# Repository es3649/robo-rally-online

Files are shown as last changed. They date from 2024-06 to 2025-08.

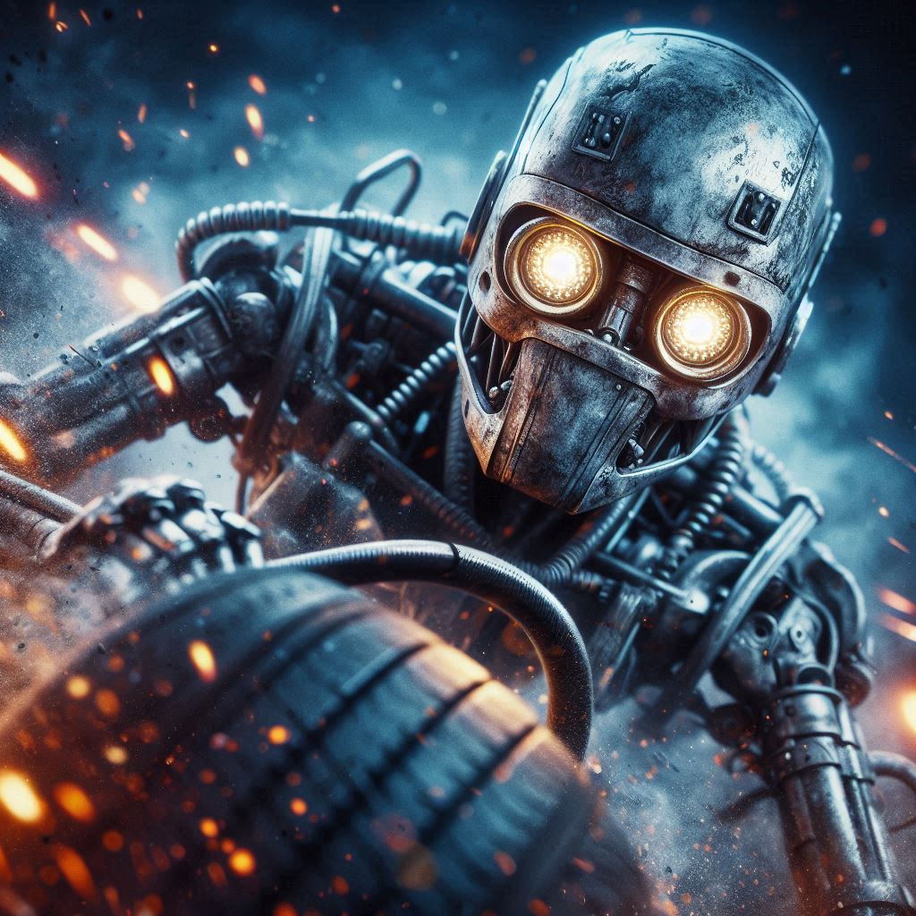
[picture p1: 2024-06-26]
shared/assets/robot_race2.jpg

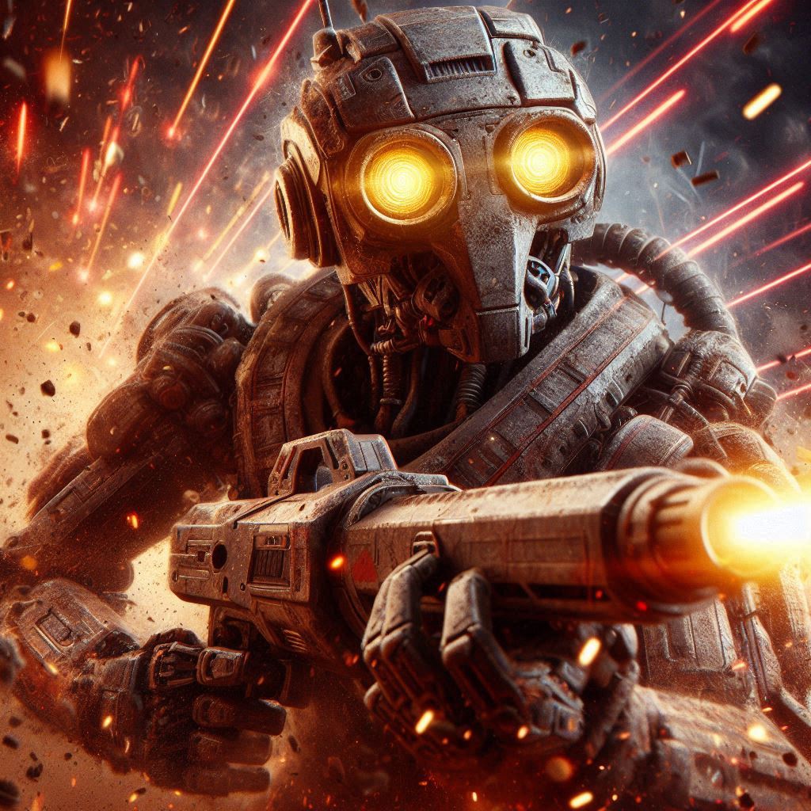
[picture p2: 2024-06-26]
shared/assets/robot_fighter.jpg

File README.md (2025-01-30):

# RoboRally Online

RoboRally Online is a Typescript/robotics implementation of the RoboRally board game, by Richard Garfield and Renegade Game Studio.

One day, while playing RoboRally, I thought to myself, _"How cool would it be if the robots on the board were actual robots, and I could actually program them?"_ so I decided to make it for real.
I started with a high-school physics knowledge of electronics, then read forums, watched videos, and bothered friends until I was able to figure out how to make it work.
This repository contains a majority of the files and code needed to bring the project to life.

**Disclaimer**: This project is not affiliated with nor endorsed by Richard Garfield nor Renegade Game Studio

## Contents

* [Contents](#contents)
* [Setup Instructions](#setup-instructions)
* [Project Structure](#project-structure)
    * [Player Client](#player-client)
    * [Host Application](#host-application)
    * [Bot Drivers](#bot-drivers)
    * [Schematics](#schematics)

## Setup Instructions

This project is the fullest stack application&mdash;all it's missing is a database.
Instructions for setting up a game (assuming the code is installed, running, and the bots are assembled) can be found in [playing.md](./doc/playing.md).
More comprehensive setup instructions, including instructions for setting up the execution environment and assembling bots, are provided in [setup.md](./doc/setup.md).

## Project Structure

The project is broken into 4 main parts:

* Player Client
* Host Application
* Bot Drivers
* Schematics

### Player Client

The Player Client, contained in the `player-client` directory, is a Vue+Vite+Pinia web application which provides a web interface for playing the game

### Host Application

The host application, in the `robo-rally-host` folder, is an Electron+Vite+Vue3 desktop application written in Typescript which provides an interface for starting the game, choosing some game settings, and managing Bluetooth connections with the robots.
It also contains a express-powered and socket.io-enabled server for hosting and joining games, and for handling communication with the players.
This server serves the Player Client.

### Bot Drivers

The bot drivers, in the `bot-drivers` directory, are a series of Arduino programs, designed to control robots over a Bluetooth connection managed by the host.

### Schematics

The `schematics` folder contains PCB and CAD schematics.

The PCB schematics are created using KiCad to model the custom boards used inside each robot.
For simplicity, there is one schematic to service all bots, and thus all robot features will be supported on each PCB.
Robots which do not support a certain feature, will simply have relevant components omitted, and will not have those components supported in their drivers.

CAD schematics are created in OnShape, and contain the 3D models for the robots.
Each of these is unique.

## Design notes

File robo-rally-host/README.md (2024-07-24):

# RoboRally Host

RoboRally Host is a desktop application made with Electron and Vite+Typescript.
It contains the Express server which serves up the compiled player-client files, it manages the websocket connections which the player-clients establish to send and receive game data, it runs the game server, and manages the Bluetooth connections to the robots.
It really is the workhorse of the entire system.

It is designed to be run on Raspberry Pi 5 with an attached touchscreen (1024x600 resolution)

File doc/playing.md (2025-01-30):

# Playing the Game

1. Connect the Pi and the players to the same Wi-Fi network
1. Set out the board
1. Start the application
1. Have the players join the game by scanning the QR code which appears on the console
    1. Players select bots and names
1. Power on the bots which will the players have selected
1. Start the game on the console
1. Follow prompts on the console to continue the game

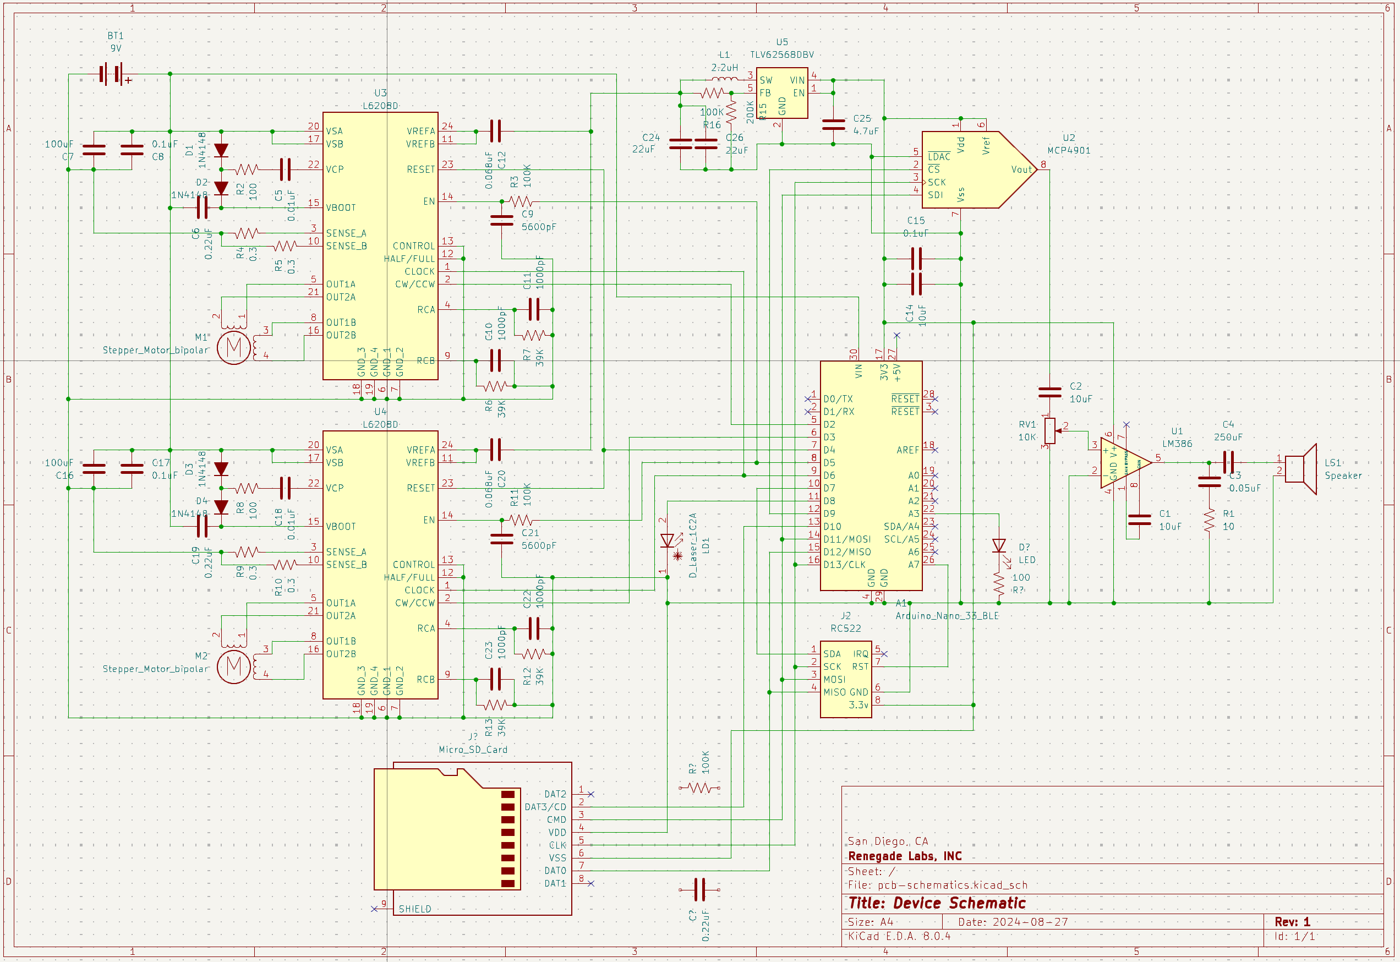
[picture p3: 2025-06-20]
player-client/src/assets/loading/schematic.png

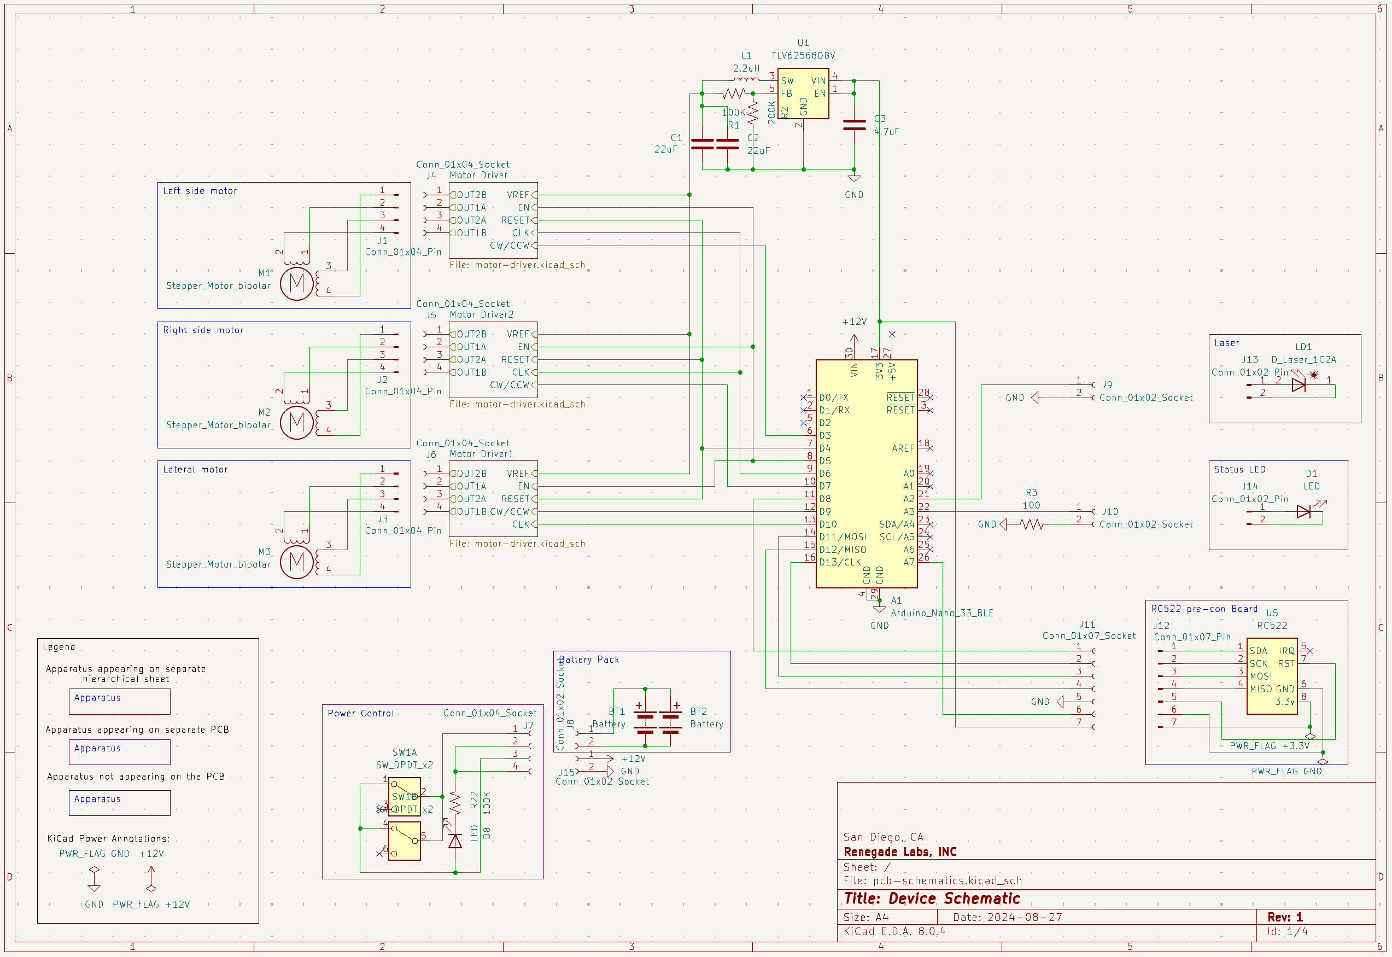
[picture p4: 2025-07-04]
player-client/src/assets/loading/schematic_sheet.png

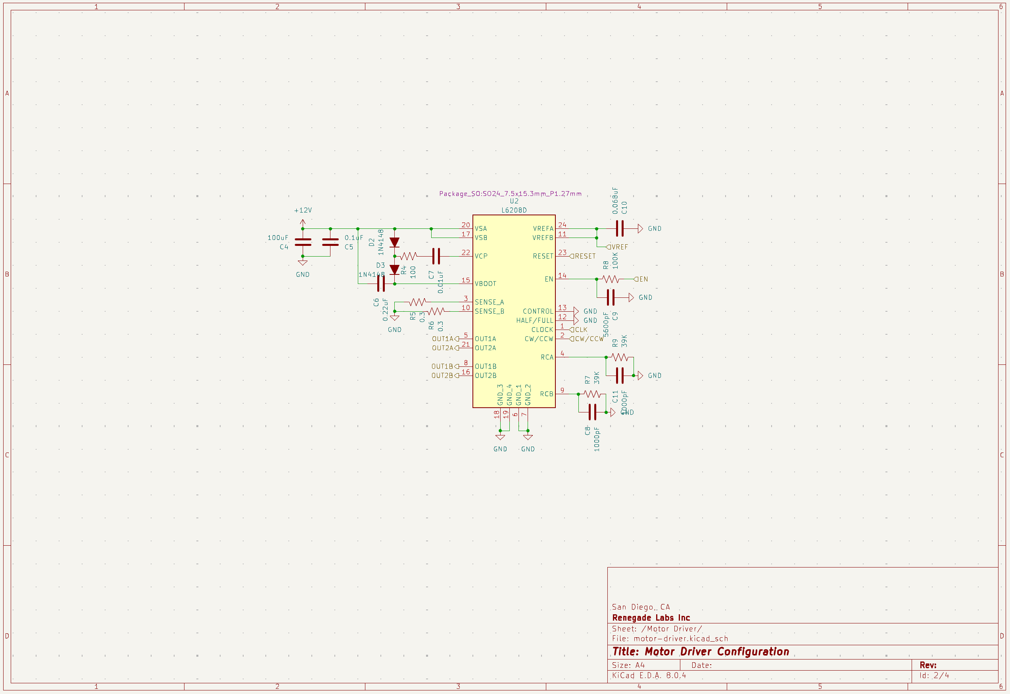
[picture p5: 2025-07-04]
player-client/src/assets/loading/motor_schematic_sheet.png

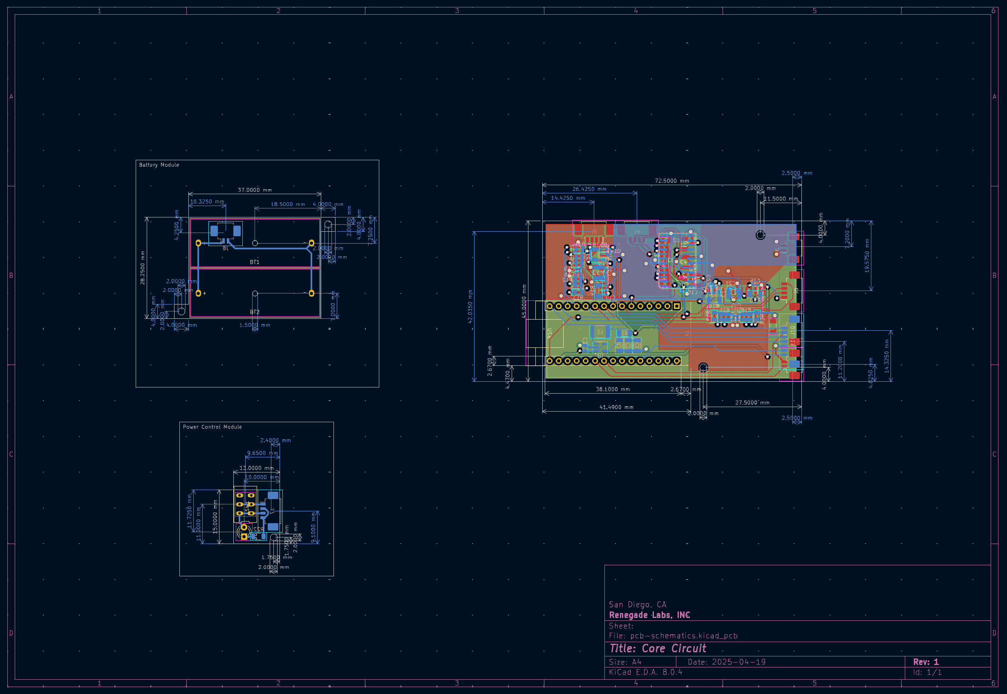
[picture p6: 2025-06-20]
player-client/src/assets/loading/PCB_sheet.png

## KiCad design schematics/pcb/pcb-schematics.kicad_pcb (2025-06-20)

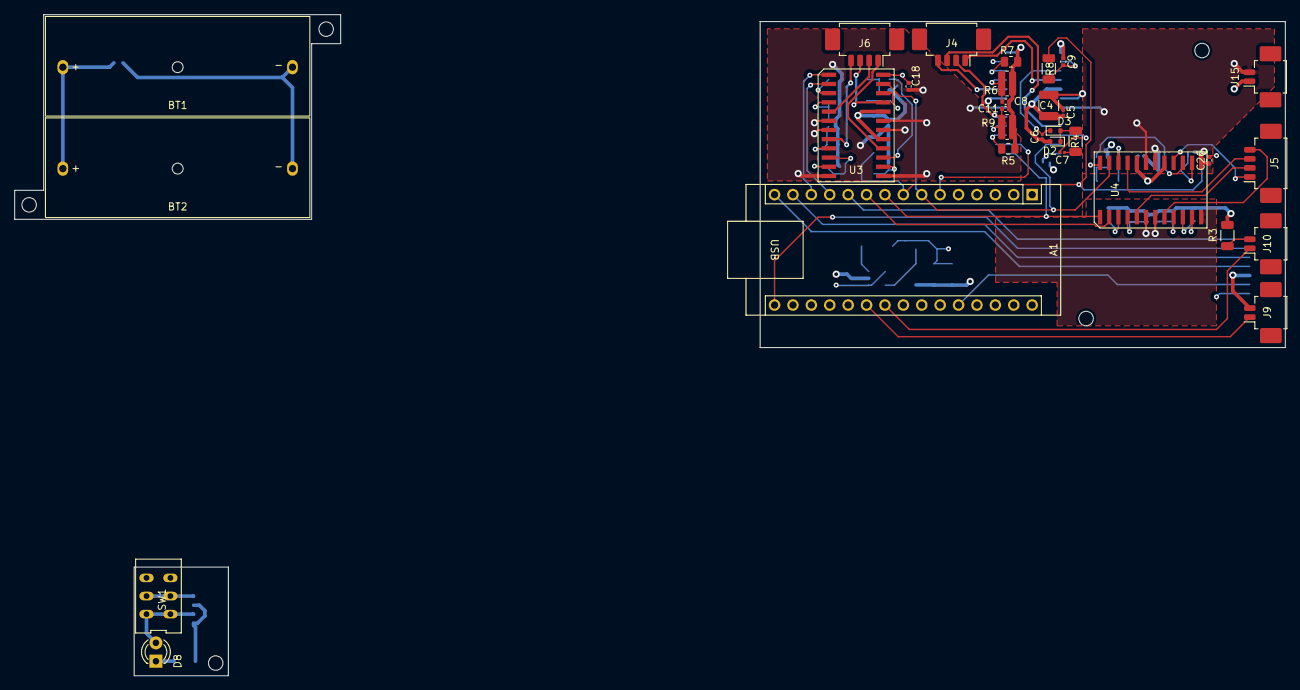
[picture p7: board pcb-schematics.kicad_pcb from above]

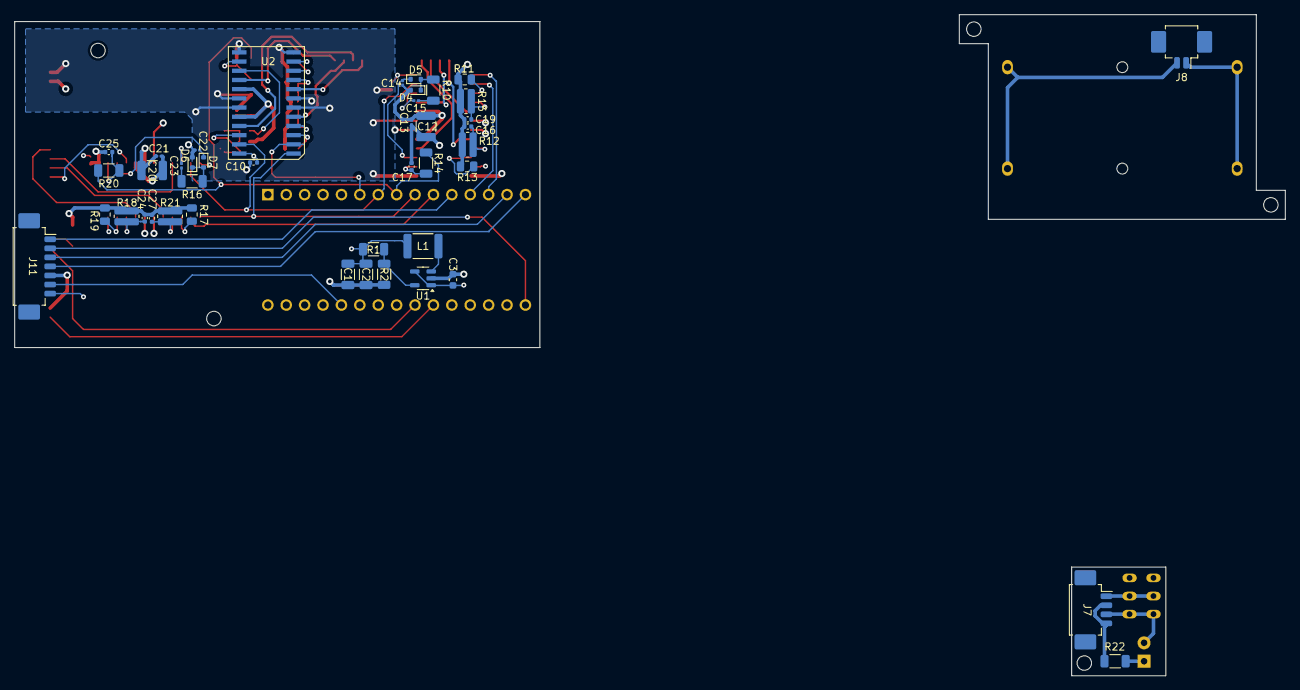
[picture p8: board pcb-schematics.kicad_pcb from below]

Board: 4 copper layers, 72.5 x 45.0 mm, 74 parts (43 on the bottom side), 66 nets.

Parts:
A1: Arduino_Nano_33_BLE; Arduino_Nano
BT1, BT2: Battery; Battery_clip-MPD_BHA23APC
C1, C2: 22uF; C_1206_3216Metric
C3: 4.7uF; C_0603_1608Metric
C4, C12, C20: 100uF; C_1210_3225Metric
C5, C13, C21: 0.1uF; C_0201_0603Metric_Pad0.64x0.40mm_HandSolder
C6, C14, C22: 0.22uF; C_0201_0603Metric
C7, C15, C23: 0.01uF; C_0201_0603Metric
C8, C11, C16, C19, C24, C27: 1000pF; C_0402_1005Metric
C9, C17, C25: 5600pF; C_0402_1005Metric
C10, C18, C26: 0.068uF; C_0402_1005Metric
D2, D3, D4, D5, D6, D7: 1N4148; D_SOD-523
D8: LED; LED_D3.0mm
J4, J5, J6, J7: Conn_01x04_Socket; Molex_PicoBlade_53261-0471_1x04-1MP_P1.25mm_Horizontal
J8, J9, J10, J15: Conn_01x02_Socket; Molex_PicoBlade_53261-0271_1x02-1MP_P1.25mm_Horizontal
J11: Conn_01x07_Socket; Molex_PicoBlade_53261-0771_1x07-1MP_P1.25mm_Horizontal
L1: 2.2uH; L_1812_4532Metric
R1, R8, R14, R20, R22: 100K; R_1206_3216Metric
R2: 200K; R_1206_3216Metric
R3, R4, R10, R16: 100; R_1206_3216Metric
R5, R6, R11, R12, R17, R18: 0.3; R_0805_2012Metric
R7, R9, R13, R15, R19, R21: 39K; R_0612_1632Metric
SW1: SW_DPDT_x2; SW-Slide_Diptronics-LSSA22
U1: TLV62568DBV; SOT-23-5
U2, U3, U4: L6208D; SO24_7.5x15.3mm_P1.27mm

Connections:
+12V: A1.30 (VIN), C4.2, C5.2, C6.1, C12.2, C13.2, C14.1, C20.2, C21.2, C22.1, D2.2 (A), D4.2 (A), D6.2 (A), J15.1, U2.17 (VSB), U2.20 (VSA), U3.17 (VSB), U3.20 (VSA), U4.17 (VSB), U4.20 (VSA)
/Motor Driver1/CLK: A1.13 (D10), U3.1 (CLOCK)
/Motor Driver1/CW/CCW: A1.12 (D9), U3.2 (CW/CCW)
/Motor Driver1/OUT1A: J6.2, U3.5 (OUT1A)
/Motor Driver1/OUT1B: J6.4, U3.8 (OUT1B)
/Motor Driver1/OUT2A: J6.3, U3.21 (OUT2A)
/Motor Driver1/OUT2B: J6.1, U3.16 (OUT2B)
/Motor Driver2/CW/CCW: A1.10 (D7), U4.2 (CW/CCW)
/Motor Driver2/OUT1A: J5.2, U4.5 (OUT1A)
/Motor Driver2/OUT1B: J5.4, U4.8 (OUT1B)
/Motor Driver2/OUT2A: J5.3, U4.21 (OUT2A)
/Motor Driver2/OUT2B: J5.1, U4.16 (OUT2B)
/Motor Driver/CLK: A1.9 (D6), U2.1 (CLOCK), U4.1 (CLOCK)
/Motor Driver/CW/CCW: A1.6 (D3), U2.2 (CW/CCW)
/Motor Driver/EN: A1.8 (D5), R8.2, R14.2, R20.2
/Motor Driver/OUT1A: J4.2, U2.5 (OUT1A)
/Motor Driver/OUT1B: J4.4, U2.8 (OUT1B)
/Motor Driver/OUT2A: J4.3, U2.21 (OUT2A)
/Motor Driver/OUT2B: J4.1, U2.16 (OUT2B)
/Motor Driver/RESET: A1.7 (D4), U2.23 (RESET), U3.23 (RESET), U4.23 (RESET)
/Motor Driver/VREF: C1.2, C2.2, C10.2, C18.2, C26.2, L1.1, R1.2, U2.11 (VREFB), U2.24 (VREFA), U3.11 (VREFB), U3.24 (VREFA), U4.11 (VREFB), U4.24 (VREFA)
GND: A1.4 (GND), A1.29 (GND), C1.1, C2.1, C3.2, C4.1, C5.1, C8.2, C9.1, C10.1, C11.2, C12.1, C13.1, C16.2, C17.1, C18.1, C19.2, C20.1, C21.1, C24.2, C25.1, C26.1, C27.2, J9.2, J11.5, J15.2, R2.1, R3.2, R5.1, R6.1, R7.2, R9.2, R11.1, R12.1, R13.2, R15.2, R17.1, R18.1, R19.2, R21.2, U1.2 (GND), U2.6 (GND_1), U2.7 (GND_2), U2.12 (HALF/FULL), U2.13 (CONTROL), U2.18 (GND_3), U2.19 (GND_4), U3.6 (GND_1), U3.7 (GND_2), U3.12 (HALF/FULL), U3.13 (CONTROL), U3.18 (GND_3), U3.19 (GND_4), U4.6 (GND_1), U4.7 (GND_2), U4.12 (HALF/FULL), U4.13 (CONTROL), U4.18 (GND_3), U4.19 (GND_4)
unnamed: A1.17 (3V3), C3.1, J11.7, U1.1 (EN), U1.4 (VIN)
unnamed: A1.21 (A2), J9.1
unnamed: A1.22 (A3), J10.1
unnamed: A1.26 (A7), J11.6
unnamed: A1.11 (D8), J11.1
unnamed: A1.14 (D11/MOSI), J11.3
unnamed: A1.15 (D12/MISO), J11.4
unnamed: A1.16 (D13/CLK), J11.2
unnamed: BT1.1 (+), BT2.1 (+), J8.1
unnamed: BT1.2 (-), BT2.2 (-), J8.2
unnamed: C7.1, R4.2
unnamed: C15.1, R10.2
unnamed: C23.1, R16.2
unnamed: D2.1 (K), D3.2 (A), R4.1
unnamed: C6.2, D3.1 (K), U2.15 (VBOOT)
unnamed: D4.1 (K), D5.2 (A), R10.1
unnamed: C14.2, D5.1 (K), U3.15 (VBOOT)
unnamed: D6.1 (K), D7.2 (A), R16.1
unnamed: C22.2, D7.1 (K), U4.15 (VBOOT)
unnamed: D8.2 (A), J7.3, SW1.1 (A), SW1.4 (A)
unnamed: D8.1 (K), R22.2
unnamed: J7.1, SW1.2 (B), SW1.5 (B)
unnamed: J7.2, J7.4, R22.1
unnamed: J10.2, R3.1
unnamed: R1.1, R2.2, U1.5 (FB)
unnamed: L1.2, U1.3 (SW)
unnamed: C9.2, R8.1, U2.14 (EN)
unnamed: C11.1, R9.1, U2.4 (RCA)
unnamed: C8.1, R7.1, U2.9 (RCB)
unnamed: R5.2, U2.3 (SENSE_A)
unnamed: R6.2, U2.10 (SENSE_B)
unnamed: C7.2, U2.22 (VCP)
unnamed: C17.2, R14.1, U3.14 (EN)
unnamed: C19.1, R15.1, U3.4 (RCA)
unnamed: C16.1, R13.1, U3.9 (RCB)
unnamed: R11.2, U3.3 (SENSE_A)
unnamed: R12.2, U3.10 (SENSE_B)
unnamed: C15.2, U3.22 (VCP)
unnamed: C25.2, R20.1, U4.14 (EN)
unnamed: C27.1, R21.1, U4.4 (RCA)
unnamed: C24.1, R19.1, U4.9 (RCB)
unnamed: R17.2, U4.3 (SENSE_A)
unnamed: R18.2, U4.10 (SENSE_B)
unnamed: C23.2, U4.22 (VCP)

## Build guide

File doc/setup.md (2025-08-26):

# Robo-Rally Online Setup

Setting up this project is super non-trivial

## Software

### Bluetooth

This project depends on the BlueZ package, which is the official Bluetooth driver for Linux development stacks.
It requires root privileges by default, so you will either need to run as root (rarely recommended), or else grant your user access to BlueZ by adding the following to `/etc/dbus-1/system.d/node-ble.conf`

```xml
<!DOCTYPE busconfig PUBLIC "-//freedesktop//DTD D-BUS Bus Configuration 1.0//EN"
  "http://www.freedesktop.org/standards/dbus/1.0/busconfig.dtd">
<busconfig>
  <policy user="__USERID__">
   <allow own="org.bluez"/>
    <allow send_destination="org.bluez"/>
    <allow send_interface="org.bluez.GattCharacteristic1"/>
    <allow send_interface="org.bluez.GattDescriptor1"/>
    <allow send_interface="org.freedesktop.DBus.ObjectManager"/>
    <allow send_interface="org.freedesktop.DBus.Properties"/>
  </policy>
</busconfig>
```

where `__USERID__` is replaces with the ID of the user which will be running the electron app.

### Port Access

The application hosts a webserver on the device.
Clients will try to access the server on port 80 (or 443 if I ever set up SSL, which I probably should).

To fix this, we ust host on 8199, and require a port forwarding on the host device to route traffic from 80 (or 443) to 8199.

On Linux, these can be set up using the `iptables` tool.
Start by enabling ip forwarding by adding this line to `/etc/sysctl.conf`
```
net.ipv4.ip_forward=1
```
then apply the changes with
```bash
sudo sysctl -p
```
Finally, apply the port forwarding rule by running
```bash
sudo iptables -t nat -A PREROUTING -p tcp --dport 80 -j REDIRECT --to-port 8199
```

If the `PORT` environment variable is set, then that port will be preferred over the process default of 8199.

### NodeJS

## Hardware

This is where things go crazy

### Motherboard Manufacture

### Bill of Materials

The following are required for assembly

* 1x Raspberry Pi 5 (or another Bluetooth-enabled Linux device)
* 6x Arduino Nano 33 BLE
* 6x Manufactured Motherboards
* 6x MicroSD cards (min 128MB)

TODO: Bill of materials for the chip

The following tools will also be needed for assembly, but will not be incorporated into the final product.

* 1x Micro-USB wire. The other end must attach to your development device (USB or USB-C)
* SMD Rework station, incl solder

### Arduino Programming

### Assembly

## Other Components

### Board

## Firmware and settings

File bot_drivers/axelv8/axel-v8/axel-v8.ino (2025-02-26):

#include <ArduinoBLE.h> // builtin
#include <SPI.h> // builtin
#include <MFRC522.h> // https://github.com/miguelbalboa/rfid

#define DEBUG true

#define BOT_NAME "Axel-V8"
#define STEPS_TO_MOVE_ONE_SPACE 100
#define STEPS_TO_ROTATE 100

#define STATUS_LED_PIN A3
#define RFID_RST_PIN A7
// #define SD_CS_PIN 10
#define DAC_CS_PIN 9
#define LASER_PIN 8
#define RFID_CS_PIN 7 
#define MTR_CLK_PIN 6
#define MTR_ENABLE_PIN 5
#define MTR_RESET_PIN 4
#define MTRL_ORIENTATION_PIN 2
#define MTRR_ORIENTATION_PIN 3

/**
 * States have the following LED status descriptions
 * CONNECTING: flashing quickly (~every 1/2 sec)    -_-_-_-_
 * DEFAULT: short flash every ~2 sec                -_______
 * SHUTDOWN: slowly breathing (~11s cycles)
 * LASER: same as DEFAULT, but the laser is on      -_______
 * RFID: two quick pulses, followed by ~1s off      -_-_____
 * ERROR: flashing slowly (~every 2 sec)            ----____
 */
namespace State {
  const uint8_t DEFAULT = 1;
  const uint8_t SHUTDOWN = 2;
  const uint8_t LASER = 3;
  const uint8_t RFID = 4;
};

uint8_t cur_state = State::DEFAULT;
uint8_t last_idempotence_code = 0;

namespace Movement {
  const uint8_t NONE = 0;
  const uint8_t MOVE_FORWARD = 1;
  const uint8_t MOVE_BACK = 2;
  const uint8_t MOVE_LEFT = 3;
  const uint8_t MOVE_RIGHT = 4;
  const uint8_t TURN_LEFT = 5;
  const uint8_t TURN_RIGHT = 6;
};

uint8_t movement = Movement::NONE;
int steps;

/******************************* BLUETOOTH SETUP *******************************/
// define the UUIDs for our characteristics
const char* SERVICE_ID                          = "346642f1-0000-49fc-a6a6-8a782eb06f26";
const char* STATE_CHARACTERISTIC                = "346642f1-0001-49fc-a6a6-8a782eb06f26";
const char* SOUND_CHARACTERISTIC                = "346642f1-0002-49fc-a6a6-8a782eb06f26";
const char* MOVEMENT_DIRECTION_CHARACTERISTIC   = "346642f1-0003-49fc-a6a6-8a782eb06f26";
const char* IDEMPOTENCY_CHARACTERISTIC          = "346642f1-0004-49fc-a6a6-8a782eb06f26";
const char* RFID_CHARACTERISTIC                 = "346642f1-0005-49fc-a6a6-8a782eb06f26";

BLEService controlService(SERVICE_ID);
BLEByteCharacteristic stateCharacteristic(STATE_CHARACTERISTIC, BLERead);
BLEByteCharacteristic soundCharacteristic(SOUND_CHARACTERISTIC, BLERead);
BLEByteCharacteristic movementDirectionCharacteristic(MOVEMENT_DIRECTION_CHARACTERISTIC, BLERead);
BLEByteCharacteristic idempotencyCharacteristic(IDEMPOTENCY_CHARACTERISTIC, BLERead);
BLEUnsignedIntCharacteristic rfidCharacteristic(RFID_CHARACTERISTIC, BLEWrite);

BLEDevice central;

void connect() {
  // if not initialized: initialize
  BLE.advertise();

  // flash the STATUS LED quickly while awaiting a connection
  do {
    central = BLE.central();
    digitalWrite(STATUS_LED_PIN, !digitalRead(STATUS_LED_PIN));
    delay(500);
  } while (!central);

  BLE.stopAdvertise();

  #ifdef DEBUG
    Serial.println("Connected to central device!");
    Serial.print("MAC Address: ");
    Serial.println(central.address());
  #endif

  updateBLEValues();
}

void updateBLEValues() {
  // check if the state code changed
  uint8_t written_idempotency;
  idempotencyCharacteristic.readValue(written_idempotency);

  if (written_idempotency != last_idempotence_code) {
    // update all the values
    stateCharacteristic.readValue(cur_state);
    movementDirectionCharacteristic.readValue(movement);
    last_idempotence_code = written_idempotency;
    if (movement != Movement::NONE) {
      move();
    }

    #ifdef DEBUG
      Serial.print("Read state: ");
      Serial.println(cur_state);
      Serial.print("Read movement: ");
      Serial.println(movement);
    #endif
  }
}

/******************************* RFID READER SETUP *******************************/
MFRC522 rfid(RFID_CS_PIN, RFID_RST_PIN); 

void readRFID() {
  static byte nuid_PICC[4];
  // if there is no card present, or we can't read it, continue
  if(!rfid.PICC_IsNewCardPresent() || !rfid.PICC_ReadCardSerial()) {
    return;
  }

  // check if this is a recognized card type
  MFRC522::PICC_Type picc_type = rfid.PICC_GetType(rfid.uid.sak);
  if (picc_type != MFRC522::PICC_TYPE_MIFARE_MINI &&
      picc_type != MFRC522::PICC_TYPE_MIFARE_1K &&
      picc_type != MFRC522::PICC_TYPE_MIFARE_4K) {
    return;
  }

  // if any byte is different, we actually got a new code
  if (rfid.uid.uidByte[0] != nuid_PICC[0] || 
      rfid.uid.uidByte[1] != nuid_PICC[1] || 
      rfid.uid.uidByte[2] != nuid_PICC[2] || 
      rfid.uid.uidByte[3] != nuid_PICC[3] ) {
    #ifdef DEBUG
      Serial.print("Detected new card. NUID tag is: ");
      Serial.println();
    #endif
    // save the most recent code
    uint32_t value = 0;
    for (uint8_t i = 0; i < 4; i++) {
      value <<= 8;
      nuid_PICC[i] = rfid.uid.uidByte[i];
      value |= rfid.uid.uidByte[i];
    }

    // write the new card value to the bluetooth characteristic
    rfidCharacteristic.writeValue(value);
  }
}

/******************************* L6208 DRIVER SETUP *******************************/
// TODO tune this: I think the technical minimum in the datasheet is 1us, but that's probably too short
#define MOTOR_STEP_DELAY_US 1000
inline void disableMotors() {
  digitalWrite(MTR_ENABLE_PIN, LOW);
}

inline void enableMotors() {
  digitalWrite(MTR_ENABLE_PIN, HIGH);
  // there is a max 1050ns delay we will need to respect before sending data signals
  delayMicroseconds(2);
}

inline void setMotorClockwise(const uint8_t& controller_pin) {
  digitalWrite(controller_pin, HIGH);
}

inline void setMotorWiddershins(const uint8_t& controller_pin) {
  digitalWrite(controller_pin, LOW);
}

void move() {
  if (movement == Movement::MOVE_FORWARD || movement == Movement::TURN_RIGHT) {
    // left motor needs to move clockwise
    setMotorClockwise(MTRL_ORIENTATION_PIN);
  } else {
    // needs to move widdershins
    setMotorWiddershins(MTRL_ORIENTATION_PIN);
  }

  if (movement == Movement::MOVE_BACK || movement == Movement::TURN_RIGHT) {
    // right motor needs to move clockwise
    setMotorClockwise(MTRR_ORIENTATION_PIN);
  } else {
    // right motor needs to move widdershins
    setMotorWiddershins(MTRR_ORIENTATION_PIN);
  }

  if (movement == Movement::MOVE_FORWARD || movement == Movement::MOVE_BACK) {
    steps = STEPS_TO_MOVE_ONE_SPACE;
  } else {
    steps = STEPS_TO_ROTATE;
  }

  // enable the motors
  enableMotors();
}

void moveStep() {
  // use the correct number of steps for forward/back movement, lateral movement, or rotation
  static int steps_taken = 0;

  // begin rotating the motors
  if (steps_taken < steps) {
    PinStatus clk_state = digitalRead(MTR_CLK_PIN);
    digitalWrite(MTR_CLK_PIN, !clk_state);
    delayMicroseconds(MOTOR_STEP_DELAY_US);
    if (clk_state == LOW) {
      steps_taken++;
    }
  } else {
    // set the clock low
    disableMotors();
    // set that there's no movement
    movement = Movement::NONE;
    // reset the step counts
    steps = 0;
    steps_taken = 0;
  }
}

/******************************* ERROR STATE DEFN *******************************/
/**
 * perpetually goes into an error state
 * (use only when an un-resolvable error occurs)
 */
void errorState() {
  while (1) {
    digitalWrite(STATUS_LED_PIN, HIGH);
    delay(2000);
    digitalWrite(STATUS_LED_PIN, HIGH);
    delay(2000);
  }
}

/******************************* SHUTDOWN STATE DEFN *******************************/
void shutdown() {
  // later: play a shutdown noise

  static int step = 1;
  static uint8_t intensity = 0;
  analogWrite(STATUS_LED_PIN, intensity);
  
  delay(10);
  if (intensity < 255 && intensity > 0) {
    intensity += step;
    analogWrite(STATUS_LED_PIN, intensity);
  } else {
    step *= -1;
  }

  // sometimes we still need to move while shutdown
  if (steps) {
    moveStep();
  }
}

/******************************* LASER STATE DEFN *******************************/
void laser() {
  // light off; laser on
  digitalWrite(STATUS_LED_PIN, LOW);
  digitalWrite(LASER_PIN, HIGH);

  // laser off, back to default
  digitalWrite(LASER_PIN, LOW);
  cur_state = State::DEFAULT;
}

/******************************* DEFAULT STATE DEFN *******************************/
void statusLEDUpdate() {
  static int last_status_led_swap = 0;
  int now = millis();
  PinStatus led_status = digitalRead(STATUS_LED_PIN);
  int diff = now - last_status_led_swap;
  switch (cur_state) {
    case State::DEFAULT:
    case State::LASER:
      if (diff < 250) {
        digitalWrite(STATUS_LED_PIN, HIGH);
      } else {
        digitalWrite(STATUS_LED_PIN, LOW);
      }
      break;
    case State::RFID:
      if (diff < 250) {
        digitalWrite(STATUS_LED_PIN, HIGH);
      } else if (diff > 250) {
        digitalWrite(STATUS_LED_PIN, LOW);
      } else if (diff > 500) {
        digitalWrite(STATUS_LED_PIN, HIGH);
      } else if (diff > 750) {
        digitalWrite(STATUS_LED_PIN, LOW);
      }
      break;
  }

  if (diff > 2000) {
    last_status_led_swap = now;
  }
}

void defaultState() {
  statusLEDUpdate();

  if (movement != Movement::NONE) {
    moveStep();
  }
}

/******************************* SETUP AND LOOP *******************************/
void setup() {
  pinMode(STATUS_LED_PIN, OUTPUT);
  pinMode(RFID_RST_PIN, OUTPUT);
  pinMode(LASER_PIN, OUTPUT);
  pinMode(RFID_CS_PIN, OUTPUT);
  pinMode(MTR_CLK_PIN, OUTPUT);
  pinMode(MTR_RESET_PIN, OUTPUT);
  digitalWrite(MTR_RESET_PIN, HIGH);
  pinMode(MTR_ENABLE_PIN, OUTPUT);
  disableMotors();
  pinMode(MTRL_ORIENTATION_PIN, OUTPUT);
  pinMode(MTRR_ORIENTATION_PIN, OUTPUT);

  digitalWrite(STATUS_LED_PIN, HIGH);
  
  
  #ifdef DEBUG
    Serial.begin(9600);
    while (!Serial) {}
    Serial.println("Resetting L6208(s)");
  #endif

  // hold the reset pin low for >1us, then raise it again
  digitalWrite(MTR_RESET_PIN, LOW);
  delayMicroseconds(15);
  digitalWrite(MTR_RESET_PIN, HIGH);

  #ifdef DEBUG
    Serial.println("L6208(s) reset");
    Serial.println("Initializing RFID reader");
  #endif
  // setup the RFID reader
  SPI.begin();
  rfid.PCD_Init();

  #ifdef DEBUG
    Serial.println("RFID reader ready");
    Serial.println("Starting Bluetooth® Low Energy");
  #endif

  if(!BLE.begin()) {
  #ifdef DEBUG
      Serial.println("Failed to start Bluetooth®!");
  #endif
    errorState();
  }

  BLE.setLocalName(BOT_NAME);
  BLE.setAdvertisedService(controlService);
  controlService.addCharacteristic(stateCharacteristic);
  controlService.addCharacteristic(soundCharacteristic);
  controlService.addCharacteristic(movementDirectionCharacteristic);
  controlService.addCharacteristic(idempotencyCharacteristic);
  controlService.addCharacteristic(rfidCharacteristic);

  stateCharacteristic.writeValue(-1);
  #ifdef DEBUG
    Serial.println("Bluetooth® Low Energy initialized");
  #endif

  // start connecting
  connect();
}

void loop() {
  // check the connection status, if we were disconnected, return to pairing mode
  if (!central.connected()) {
    // switch back to connecting state
    connect();
  } else {
    // update values from BLE
    updateBLEValues();
  }

  statusLEDUpdate();

  switch (cur_state) {
  case State::DEFAULT:
    defaultState();
    break;
  case State::SHUTDOWN:
    shutdown();
    break;
  case State::LASER:
    laser();
    break;
  case State::RFID:
    readRFID();
    break;
  default:
    cur_state = State::DEFAULT;
    break;
  }
}

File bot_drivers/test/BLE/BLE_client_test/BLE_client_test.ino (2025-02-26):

// we set up the Arduino as a BLE peripheral device
// Code is adapted from a public-domain Arduino tutorial
// https://docs.arduino.cc/tutorials/nano-33-ble-sense/ble-device-to-device/

#include <ArduinoBLE.h>

// #define DEBUG

#define RED_PIN A0
#define GREEN_PIN A2
#define BLUE_PIN A4
#define STATUS_PIN 13

const char* SERVICE_ID                          = "346642f1-48ef-0000-a6a6-8a782eb06f26";
const char* RED_CHARACTERISTIC                  = "346642f1-48ef-0001-a6a6-8a782eb06f26";
const char* GREEN_CHARACTERISTIC                = "346642f1-48ef-0002-a6a6-8a782eb06f26";
const char* BLUE_CHARACTERISTIC                 = "346642f1-48ef-0003-a6a6-8a782eb06f26";


BLEService controlService(SERVICE_ID);
BLEByteCharacteristic redCharacteristic(RED_CHARACTERISTIC, BLERead | BLEWrite);
BLEByteCharacteristic greenCharacteristic(GREEN_CHARACTERISTIC, BLERead | BLEWrite);
BLEByteCharacteristic blueCharacteristic(BLUE_CHARACTERISTIC, BLERead | BLEWrite);

void setup() {
  pinMode(RED_PIN, OUTPUT);
  pinMode(GREEN_PIN, OUTPUT);
  pinMode(BLUE_PIN, OUTPUT);

  analogWrite(RED_PIN, 128);
  delay(500);
  analogWrite(GREEN_PIN, 128);
  delay(500);
  analogWrite(BLUE_PIN, 128);
  delay(500);
  analogWrite(RED_PIN, 255);
  delay(500);
  analogWrite(GREEN_PIN, 255);
  delay(500);
  analogWrite(BLUE_PIN, 255);
  delay(500);
  analogWrite(RED_PIN, 0);
  analogWrite(GREEN_PIN, 0);
  analogWrite(BLUE_PIN, 0);

#ifdef DEBUG
  Serial.begin(9600);
  // wait for serial connection
  while (!Serial);
#endif

  if (!BLE.begin()) {
#ifdef DEBUG
    Serial.println("- Starting Bluetooth® Low Energy module failed!");
#endif
    while (1);
  }

  BLE.setLocalName("Arduino Nano 33 BLE (peripheral)");
  BLE.setAdvertisedService(controlService);
  controlService.addCharacteristic(redCharacteristic);
  controlService.addCharacteristic(greenCharacteristic);
  controlService.addCharacteristic(blueCharacteristic);
  BLE.addService(controlService);
  redCharacteristic.writeValue(0);
  greenCharacteristic.writeValue(0);
  blueCharacteristic.writeValue(0);
  digitalWrite(STATUS_PIN, HIGH);
  BLE.advertise();


#ifdef DEBUG
  Serial.println("Arduino Nano 33 BLE (Peripheral Device)");
  Serial.println("  ");
#endif
}

void loop() {
  BLEDevice central = BLE.central();
#ifdef DEBUG
  Serial.println("- Discovering Central Device");
#endif
  delay(500);

  if (central) {
    digitalWrite(STATUS_PIN, LOW);
#ifdef DEBUG
    Serial.println("* Connected to central device!");
    Serial.print("* Device MAC address: ");
    Serial.println(central.address());
    Serial.println("  ");
#endif

    while (central.connected()) {
      if (redCharacteristic.written()) {
        analogWrite(RED_PIN, redCharacteristic.value());
      }
      if (greenCharacteristic.written()) {
        analogWrite(GREEN_PIN, greenCharacteristic.value());
      }
      if (blueCharacteristic.written()) {
        analogWrite(BLUE_PIN, blueCharacteristic.value());
      }
    }

#ifdef DEBUG
    Serial.println("* Disconnected from central device!");
#endif
    digitalWrite(STATUS_PIN, HIGH);
    analogWrite(RED_PIN, 0);
    analogWrite(GREEN_PIN, 0);
    analogWrite(BLUE_PIN, 0);
  }
}

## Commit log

2024-07-02 wire up host.vue
2024-08-06 added board data models and board data files
2024-08-14 Data model work for movements and boards
2024-08-16 adds board loader and renderer
2024-08-22 socket connection is active
2024-10-14 changed orientation of turning conveyors
    outgoing direction is always forward
2024-10-17 adds hardware files
    also updates a test
    [pcb-schematics.kicad_pcb, pcb-schematics.kicad_sch]
2024-10-18 adds conv_LR and board_loader tests
2024-10-18 add test data boards
2024-10-27 added tests and board element activation
2024-11-22 schematic and driver rewrite
    [pcb-schematics.kicad_pcb, pcb-schematics.kicad_sch]
2024-11-28 update algos to use movement frame
2024-11-28 more frame rewriting
    [pcb-schematics.kicad_sch]
2024-11-29 final frame updates
2025-02-07 initial draft
    missing status LED, state changes
    BLE-related compile errors
    [axel-v8.ino]
2025-02-08 axel driver rough draft finished
    desparately needs testing
2025-02-26 adds BLE test and test schematics
    [BLE Test Schematic.kicad_sch, L6208 Test Schematic.kicad_sch, rfid Test Schematic.kicad_sch]
2025-04-29 KiCad schematics at manufacture
    [audio.kicad_sch, memory.kicad_sch, motor-driver.kicad_sch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]
2025-06-20 polished Mobile UI
    [pcb-schematics.kicad_pcb]
